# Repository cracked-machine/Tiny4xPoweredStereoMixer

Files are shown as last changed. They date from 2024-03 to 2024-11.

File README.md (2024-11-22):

HTML version of this page can be found [here](https://cracked-machine.github.io/Tiny4xPoweredStereoMixer/)

# Tiny 4 Channel Powered Stereo Mixer

A Tiny form-factor 4-channel stereo mixer for use with TV/PC/Turntable/Amplifer

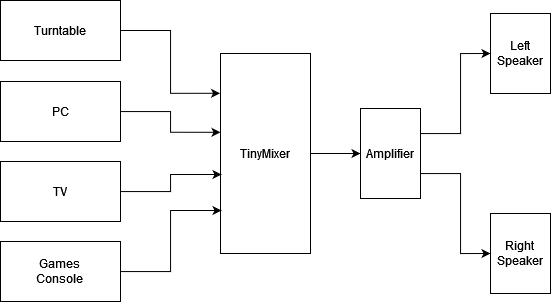
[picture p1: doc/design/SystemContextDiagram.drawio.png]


## Requirements

1. 4 stereo inputs
2. 1 stereo output
3. Inputs will all use stereo RCA/Phono connectors
4. volume controls for each of the 4 input channels
5. volume controls should be mounted in the front of the case
6. External power input shall be 9V DC
7. Internal power supply shall be +/-9V DC
8. Input signals shall be buffered
9. Volume controls for each channel shall  be independant and not subtract gain from the other channels.
10. Cross-talk between channels should be minimised.
  
## Top level Design

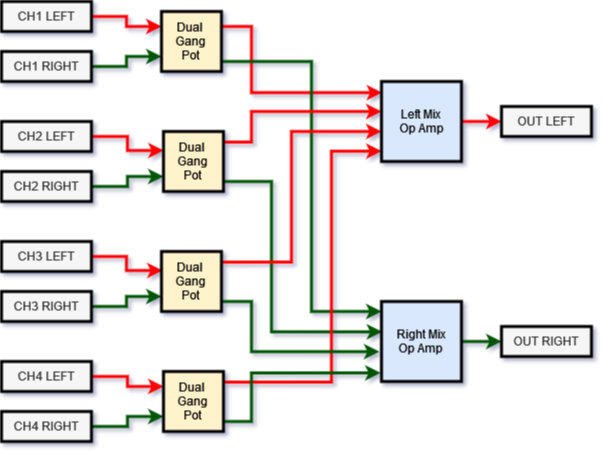
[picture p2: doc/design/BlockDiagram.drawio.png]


The opamps shall use [TL072](https://www.ti.com/lit/gpn/TL072H)

Using opamps to buffer the input signals and mix the channels together will ensure that the volume of each channel can be mixed independently from the others.

The design will implement an inverting opamp "virtual  ground" topology. The virtual ground refers to the inputs of the mixing opamp: the non-inverting input will be referenced to ground, which means the voltage at both opamp inputs will be referenced to ground because the potential _difference between inputs_ will always try to be zero. The absence of voltage at these inputs will prevent cross-talk between the channels. There is a far superior explanation of this concept at [sound-au.com](https://sound-au.com/articles/audio-mixing.htm#s3)

## Power Stage Design

The old PSU design for Rev A/B can be found in [OLDPSU.md](OLDPSU.md).

The negative voltage rail is generated from the positive rail using a [TPS54202](https://www.ti.com/lit/ds/symlink/tps54202.pdf) SMPS IC. This is normally a buck regulator. However, it can be configured to generate a negative voltage when pin 2 is clamped to ground, forcing pin 1 to a negative voltage.

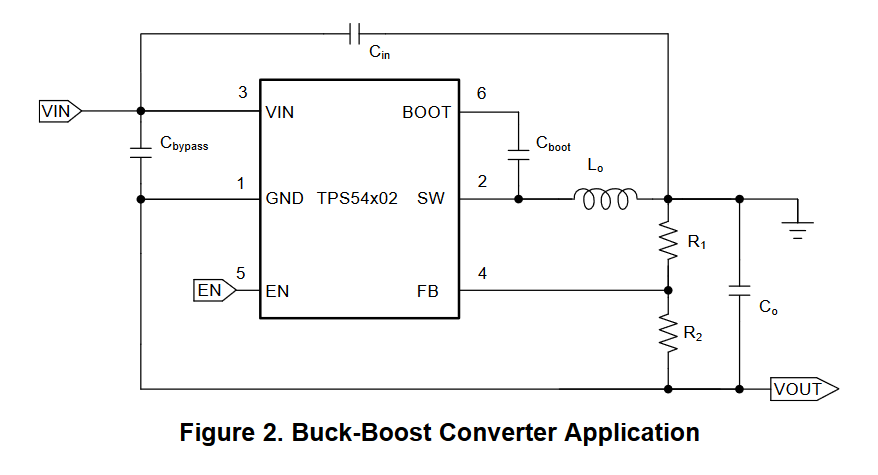
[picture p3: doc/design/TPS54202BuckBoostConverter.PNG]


Further details can be found in the [SLVA933](https://www.ti.com/lit/an/slva933/slva933.pdf) app note

### Soft Start

Unlike the LM2611, the TPS54202 has an internal soft start circuit. This can be seen in the Function Block Diagram of the [TPS54202](https://www.ti.com/lit/ds/symlink/tps54202.pdf) datasheet.

### Output Voltage 

Output voltage is selected using the voltage divider between pins 2 and 1, creating feedback into pin 4. This is very similar to the normal operation of this IC.

### Current Draw and Load Regulation

Output ripple is shown in the [SLVA933](https://www.ti.com/lit/an/slva933/slva933.pdf) app note as 5mV at no load and 20mV at 0.8A (see pages 21-22).

For my own test I [created a small board](https://github.com/cracked-machine/tps54202_inverting_breakout).
The original layout example with the new configuration violated the layout guiidelines from the [TPS54202](https://www.ti.com/lit/ds/symlink/tps54202.pdf) datasheet and proved to be noisy (240mV @ 0.6A). A second revision was made with a better layout that observed the guideline and was a significant improvement (80mv @ 0.6A).

Load regulation was around 5%, dropping from 12V to 11.4V @ 0.6A.

These results were acceptable so this PSU design was used.

## Schematics

<object data="doc/design/Tiny4xPoweredStereoMixer.pdf" type="application/pdf" width="100%" height="1000px">
    <embed src="doc/design/Tiny4xPoweredStereoMixer.pdf">
        <p>This browser does not support PDFs. Please download the PDF to view it: <a href="doc/design/Tiny4xPoweredStereoMixer.pdf">Download PDF</a>.</p>
    </embed>
</object>

## Layout

I used a 4 layer board so I could have a layer per voltage rail. This makes routing the traces significantly easier. I kept the board dimensions below 10cm to minimize manufacture costs. 

[Interactive BOM](https://cracked-machine.github.io/Tiny4xPoweredStereoMixer/doc/design/ibom.html)

## Enclosure

I abandoned the 3D printed enclosure idea and made the PCB to fit this [Hammond RM2005MTBK](https://www.hammfg.com/part/RM2005MTBK) clam shell enclosure.

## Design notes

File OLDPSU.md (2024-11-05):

## Power Stage Design

To power the buffer and mixer opamps, the design will need a power stage that supports 

1. Bi-polar or symmetric voltage rails that will allow "rail-to-rail" positive and negative headroom for the +/- audio signal.
2. Enough current for 5 (4 input + 1 mix) dual channel opamps. 

The simplest method for creating a negative voltage rail is....tonot create a negative voltage rail! In other words: use a voltage divider to create DC bias mid-point at the positive voltage rail. This has the effect of level-shifting the operating point of the opamp so that the ground reference is halfway between 0 volts and the positive rail. This requires only passive components - which is cheap - but also complicates the opamp design and can create issues with the opamp behaviour itself. You also have to be careful to filter out the DC from the input and output to prevent "pops" and damage to other devices such as speakers. I'm not a fan for these reasons. 

A better way is to actually create a new negative voltage rail from the existing positive rail. 

You can do this easily with a charge pump voltage regulator. This is an inductorless topology - already a benefit - but has very limited current capabilities - usually only 10-40mA - and is unregulated. This means the generated negative voltage is easily pulled down by the load if it consists of more than a couple of opamps. In practical terms, you could require a charge pump circuit for each opamp channel. Its also recommended to put a passive low pass filter on each charge pump output to prevent ripple. Each charge pump circuit requires roughly 6 components. In total that could be lot of components when you multiply that per opamp, per channel.

In the end I settled on the Cuk regulator topology using the [LM2611](https://www.ti.com/lit/ds/symlink/lm2611.pdf) converter IC. This is a buck-boost type regulator with an inverted output rail. And it comes in a tiny SOT-23 footprint!

Here is the reference design from the datasheet. 

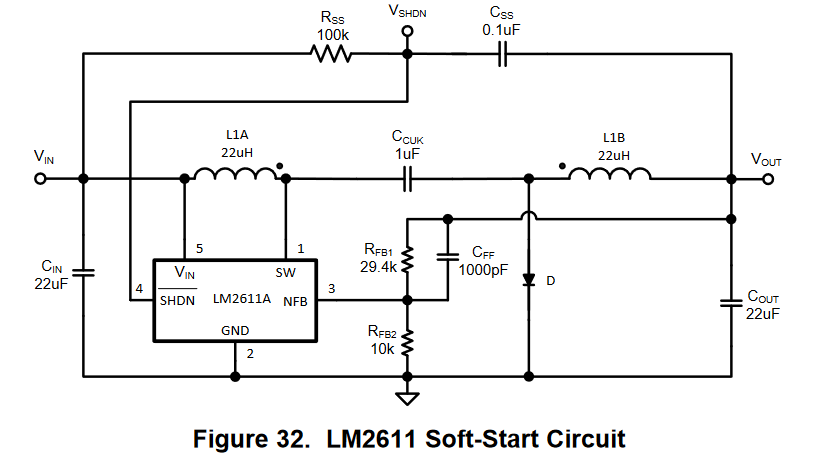
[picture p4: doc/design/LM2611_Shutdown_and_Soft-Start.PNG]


### Soft Start

Since the IC doesn't contain a soft-start feature, required additional circuitry is shown in the image above. Without the soft-start, the in-rush current will significantly exceed the current consumption specification. In fact, it tripped the lab power supply current protection; I thought the board had a short. I had to adjust the current protection to to more than 1 Amp to allow the circuit to power up correctly! Not great if you're trying to prevent lab accidents. Adding the soft-start circuitry meant that the board powered up peaking at 60mA...which is a massive drop and far mroe acceptable. Below is a screenshot of the scope capture. Negative power rail from the [LM2611](https://www.ti.com/lit/ds/symlink/lm2611.pdf) is Yellow, output signal is shown in Blue. The power rail is now much more gradual, rather than a sudden off-on transition. The datasheet implied there would still be a voltage spike at the peak of the turn on transtition but looking at the capture below, it would seem that the voltage spike with the soft-start has also been minimised greatly.

However, a large voltage spike remains on the output signal when the board is powered up. This is the culprit for the pop or thump you often hear in the output device speakers. Not sure what is the best solution here: Maybe caps on the output path, maybe delayed opamp start or maybe just turn the board on __before__ any down stream amplifiers.



### Output Voltage 

The output voltage can be adjusted using the negative feedback resistors RFB1 and RFB2.
Rather unhelpfully the datasheet did not contain the equation to calculate the resistor divider values. I found the equation on a post in the TI forums. Maybe this is EE101 but I can't reconcile that omission in my head.

|VREF|RFB1|RFB2|VOUT|
|-|-|-|-|
|-1.23v|2.2K|22k|VREF * (1 + (RFB2/RFB1)  = -13.5v|

Note, that the resistors must not exceed 50Kohm. According to the datasheet this is due to leakage at the NFB pin.

Using common resistor values it was only possible to reach just under 12v or quite a bit over. So I opted for the latter. Better to have a larger power supply swing than too little. It also gives some allowance for load regulation.

### Current Draw and Load Regulation

The application curve from the datasheet shows that with -12V output, the max current it could provide would be 400mA.

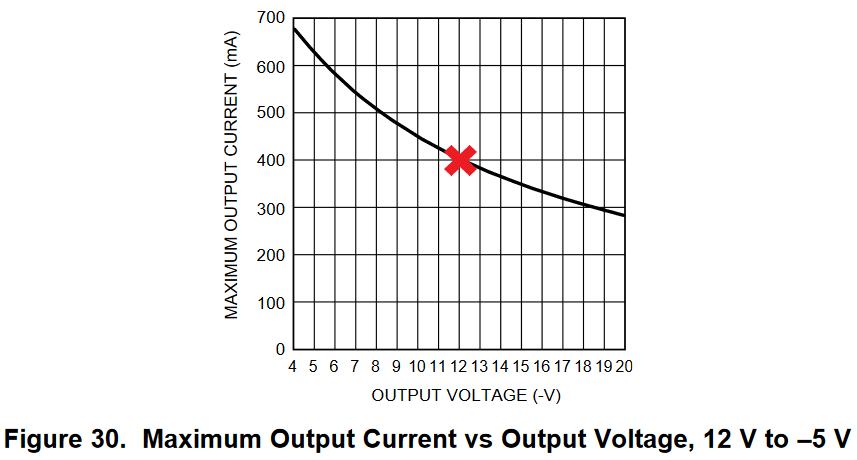
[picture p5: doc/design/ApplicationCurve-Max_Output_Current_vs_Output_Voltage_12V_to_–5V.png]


Bearing in mind the quiescent voltage of each TL072 opamp is only 1.2mA, this is overkill. However, during active use, the current will certainly be higher. 

The datasheet boasts `Better Regulation Than a Charge Pump` but then fails to offer any evidence elsewhere in the datasheet. I have no doubt that this claim is broadly true - charge pumps have abysmal load regulation. However, I'm always sceptical about the claims of load regulation on these regulator IC's. Usually when a company omits test results from the datasheet it's because the results were not so great.  

Below are the load regulation test results from 10mA to 400mA. Test was run using a [TENMA 72-13210](https://uk.farnell.com/tenma/72-13210/dc-electronic-load-prog-30a-120v/dp/2848407)

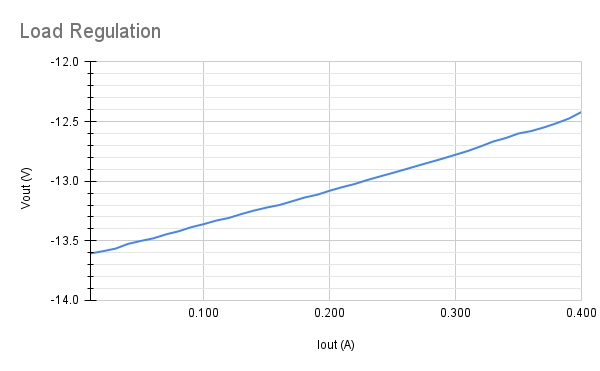
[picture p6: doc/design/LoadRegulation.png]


The negative voltage rail dropped by ~1.2V at the max load of 400mA, which is a 10% drop. That's actually not __too__ bad. Although if I had picked < 12V output I might not be so forgiving. Still, better than a charge pump...

---

Final note on the Cuk topology: There don't appear to be many IC's out there that support this type of regulator. Either it's overlooked or it has some major drawback that I'm missing here.

I noticed later it is possible to create an inverting regulator from a synchronous buck regulator.  [See this app note from TI](https://www.ti.com/lit/an/slva458b/slva458b.pdf). However, there are significant limitations:

- the input voltage
needs to be higher than the minimum required voltage for the device
- The maximum allowable output
voltage is limited by the maximum Vdev minus the maximum input voltage.
- The maximum load current cannot be more than the maximum current through the internal switches.

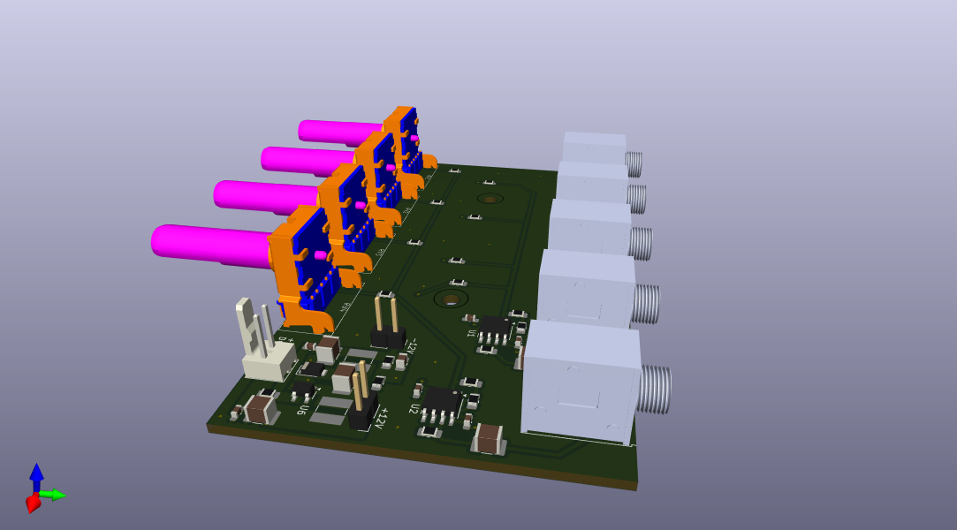
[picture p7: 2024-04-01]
doc/design/Tiny4xPoweredStereoMixerRender.png

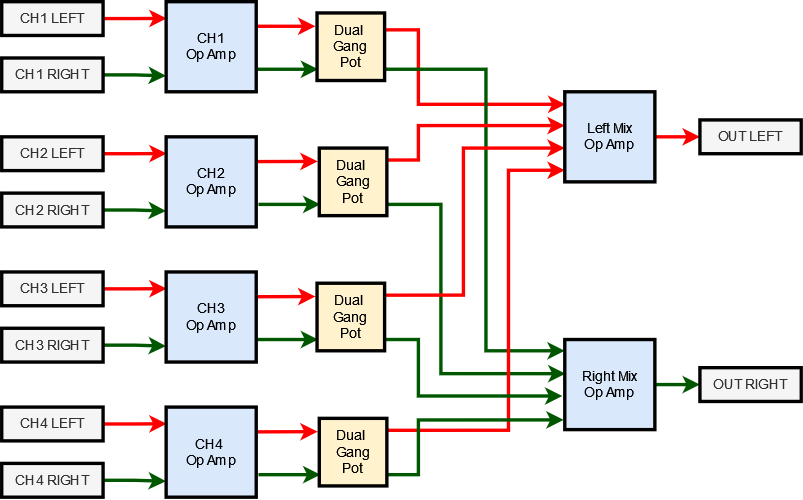
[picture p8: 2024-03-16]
doc/design/BlockDiagram.png

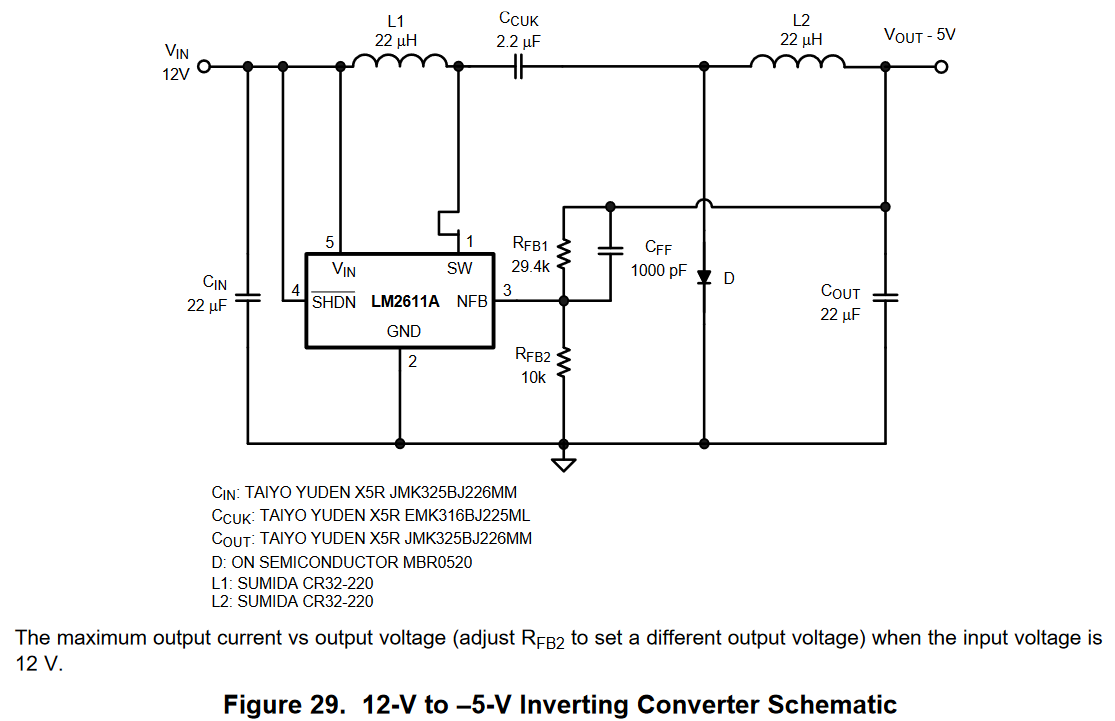
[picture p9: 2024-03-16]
doc/design/12V_to_–5V_Inverting_Converter.PNG

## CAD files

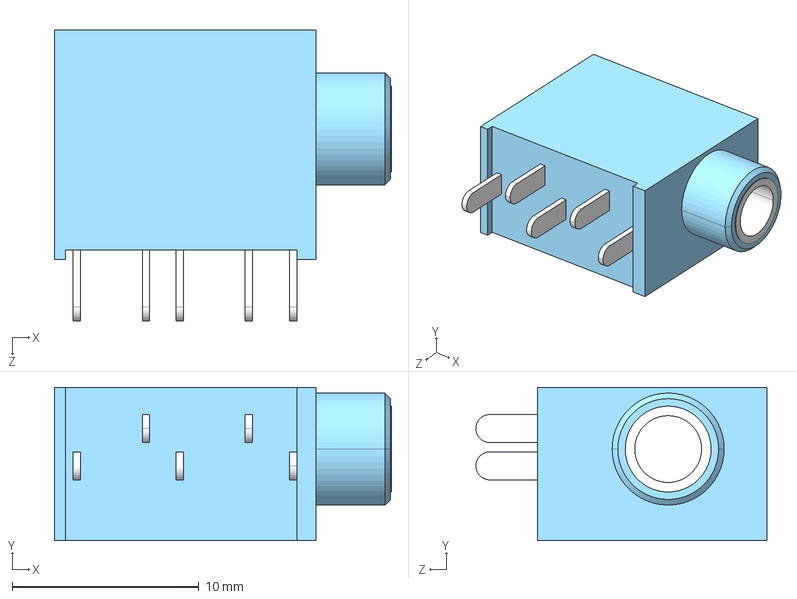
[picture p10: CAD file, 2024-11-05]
kicad/Footprints/Same_Sky_SJ1-3535NG-BE.step
18.1 x 8.20 x 15.6 mm

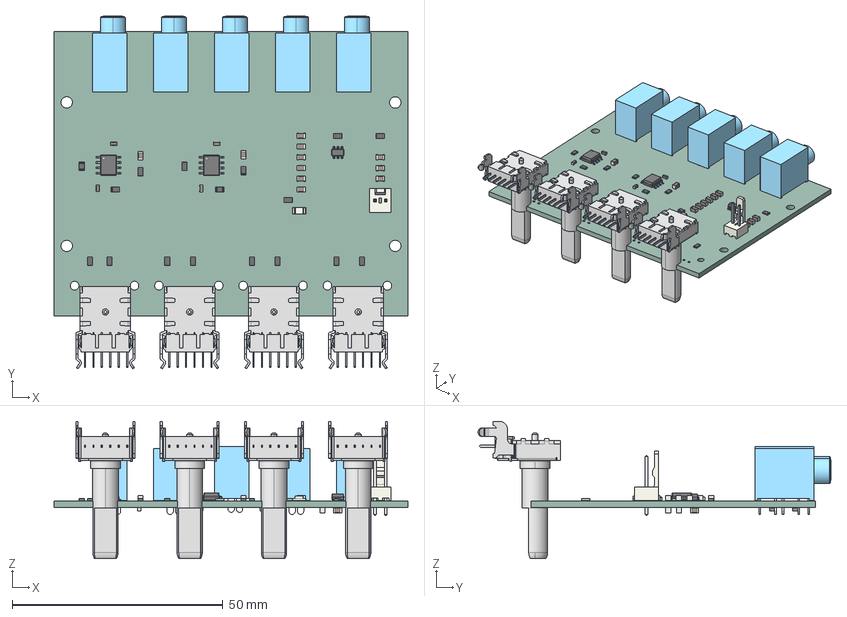
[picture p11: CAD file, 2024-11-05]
kicad/Tiny4xPoweredStereoMixer.step
84.0 x 83.7 x 32.6 mm
R_0805_2012Metric x 17
C_0805_2012Metric x 14
SOIC_8_39x49mm_P127mm x 2
C_0603_1608Metric x 12
CUI_DEVICES_SJ1-3535NG-BE x 5
SOT_23_6
Molex_AE_6410_02A
Tiny4xPoweredStereoMixer 1.33.1 x 4
LED_1206_3216Metric
Tiny4xPoweredStereoMixer_PCB

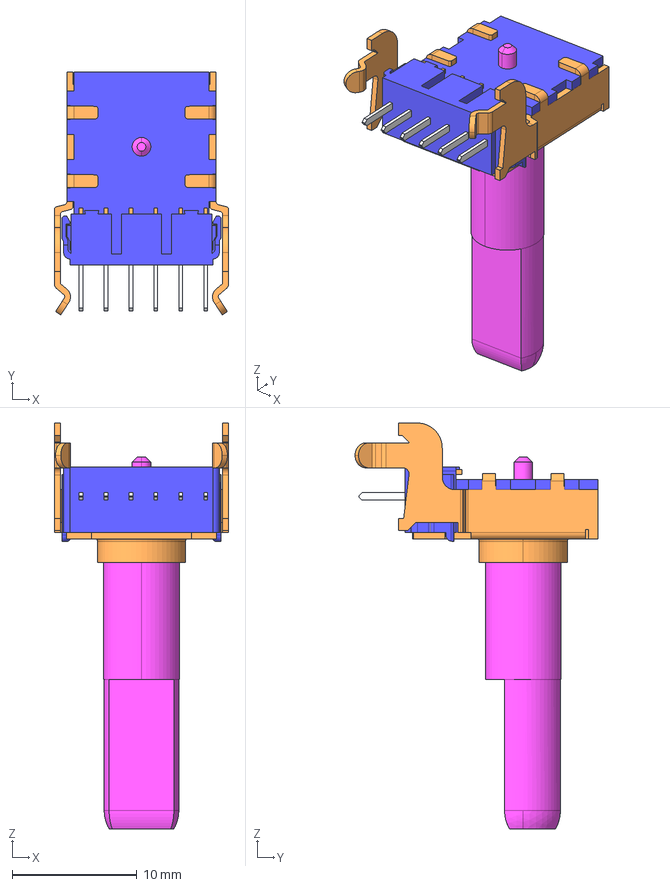
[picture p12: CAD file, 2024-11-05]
kicad/Footprints/RK12L12-F30H2.STEP
14.0 x 19.5 x 32.6 mm

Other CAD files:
kicad/Footprints/RK12L12-F30H.STEP

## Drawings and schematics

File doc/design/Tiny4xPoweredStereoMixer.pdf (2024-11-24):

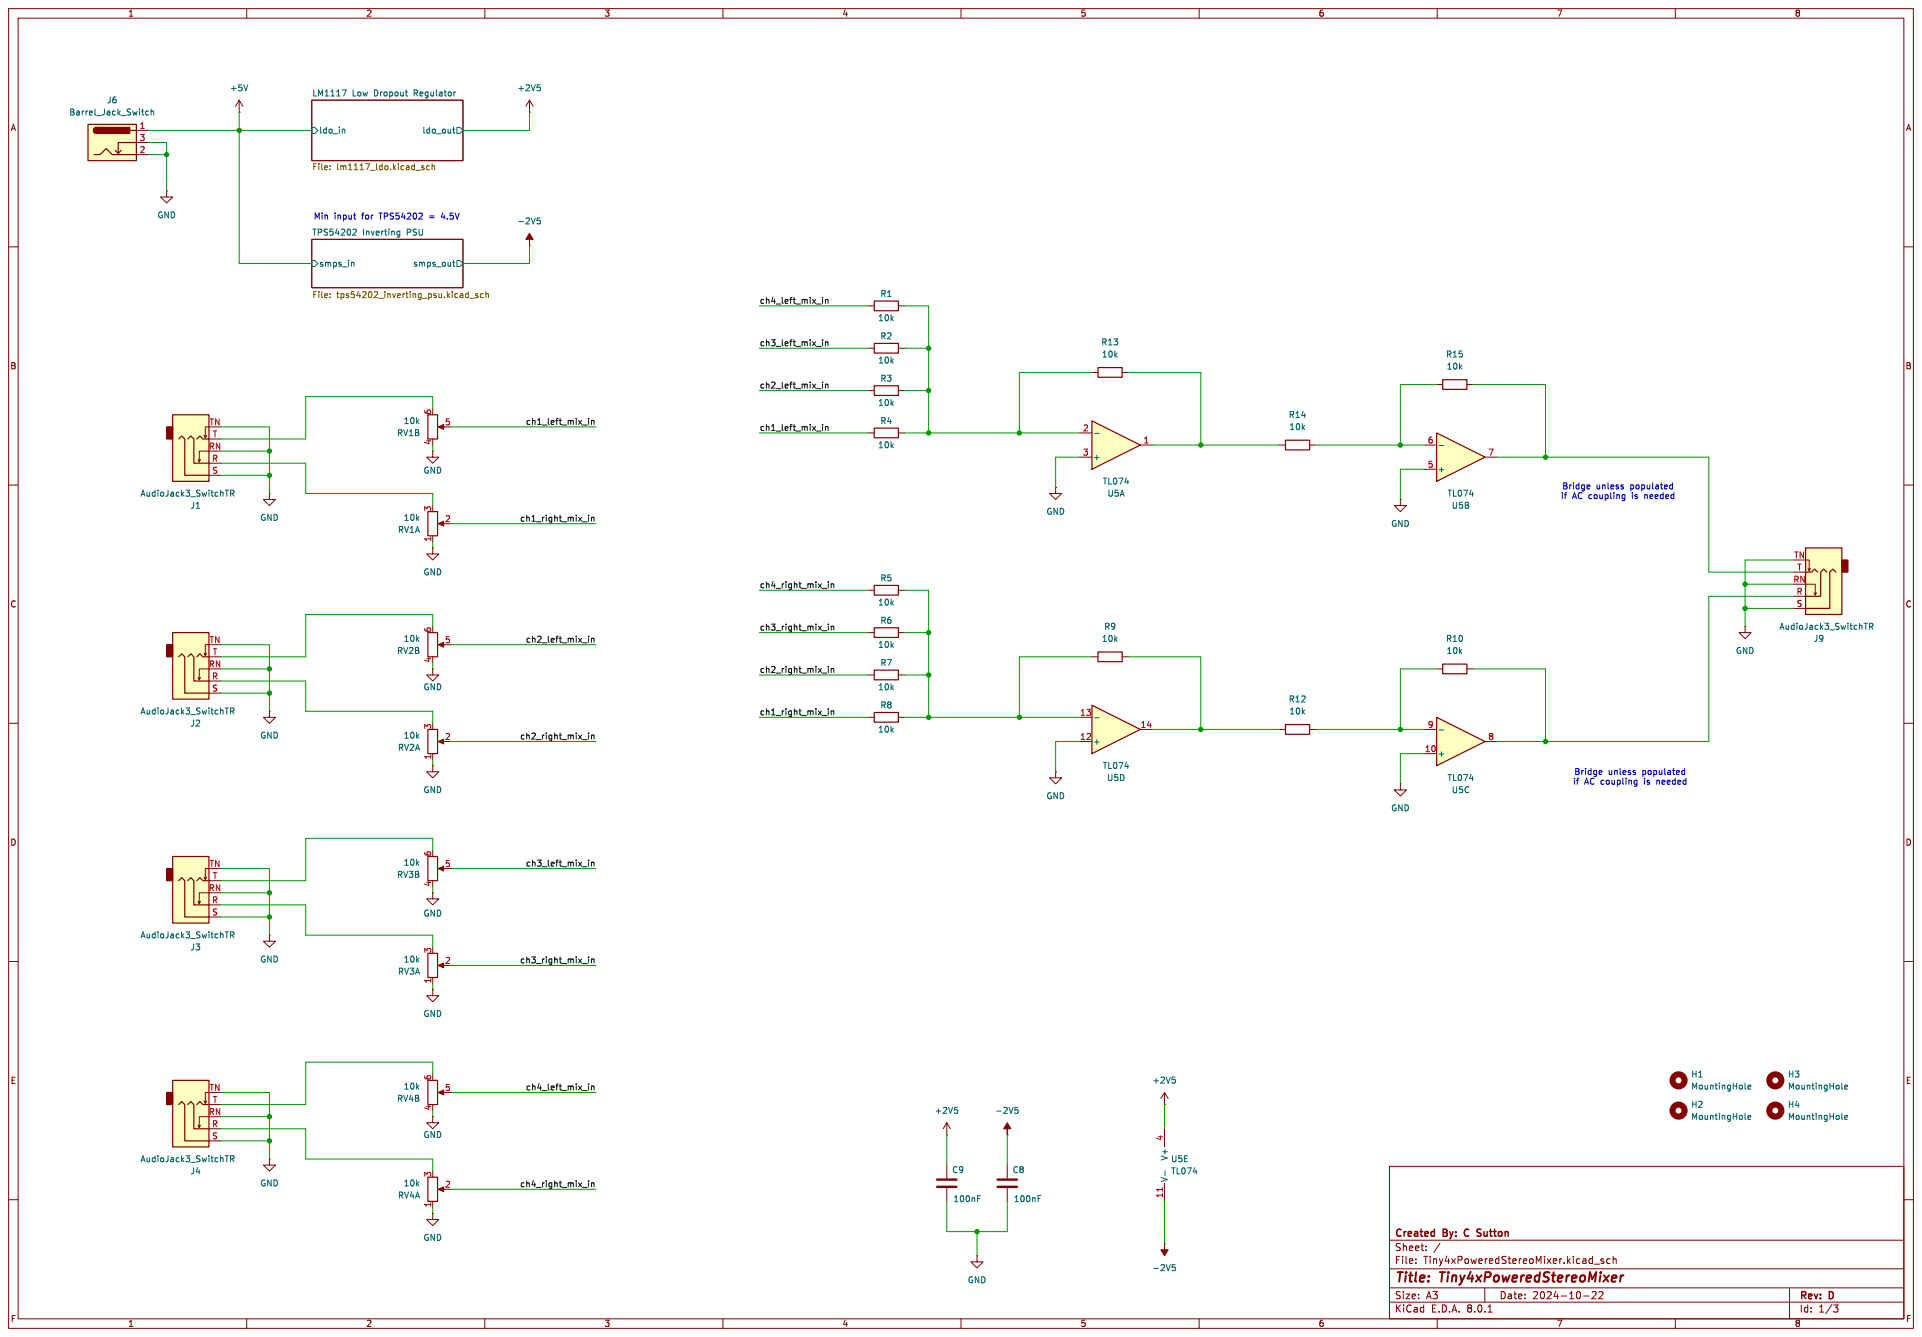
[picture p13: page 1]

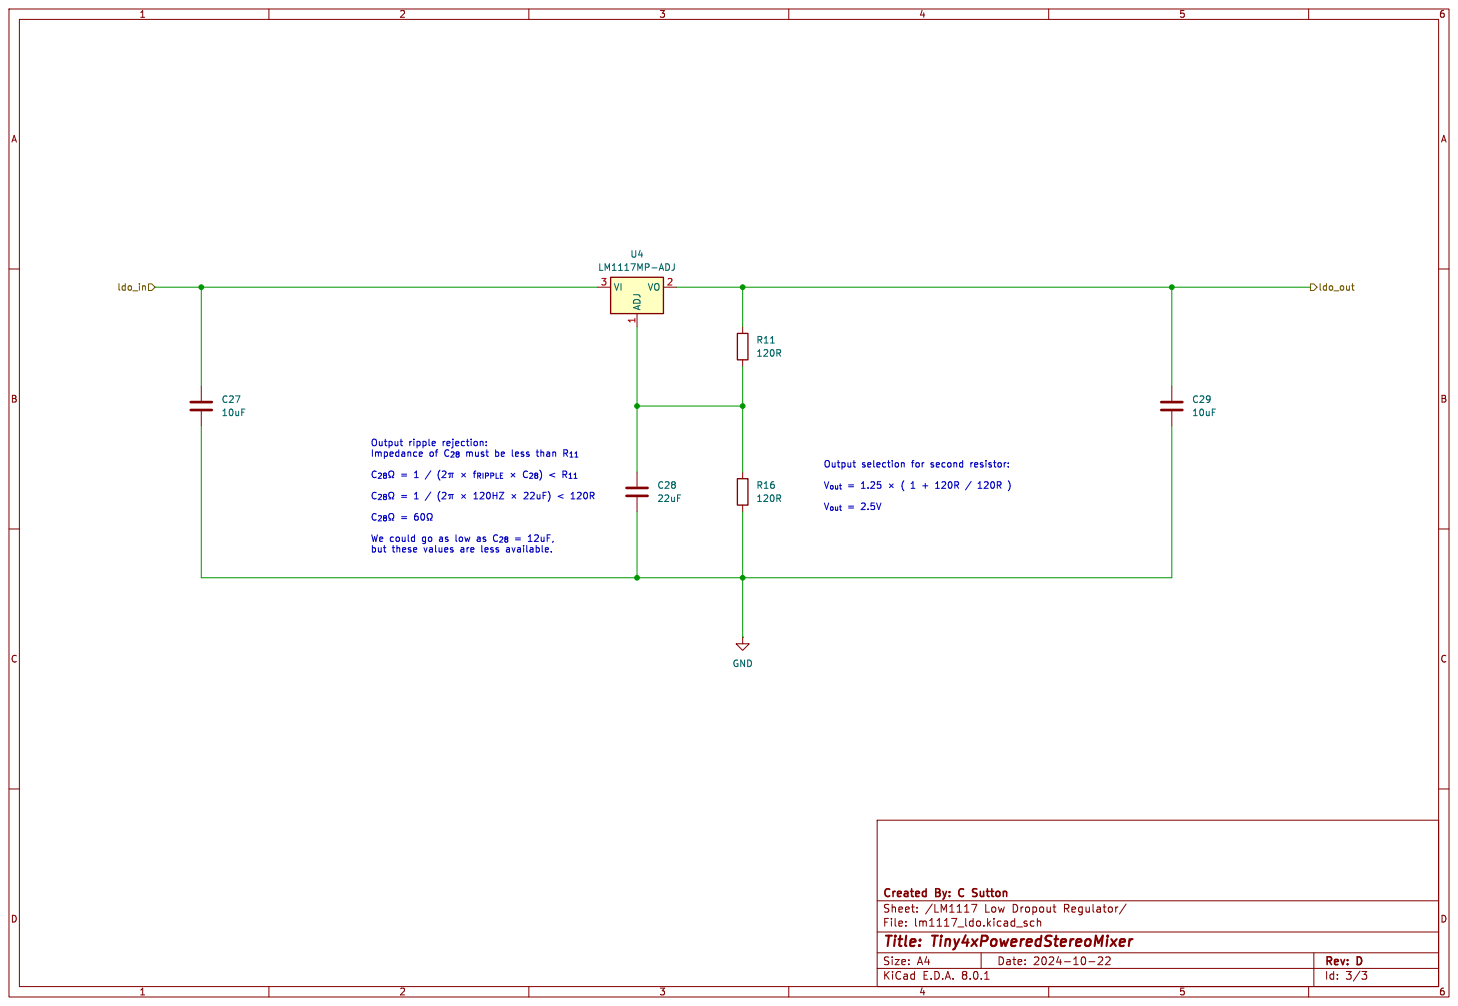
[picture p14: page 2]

þÿC_{28}© = 1 / þÿ(2Àþÿ×f_{RIPPLE} þÿ×C_{28})< R_{11}

þÿC_{28}© = 1 / þÿ(2Àþÿ×120HZ þÿ×22uF) < 120R

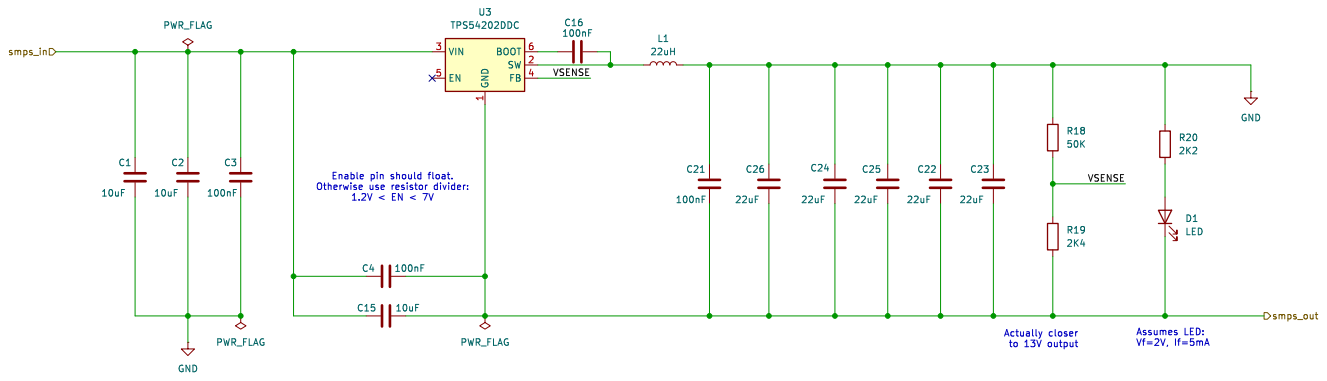
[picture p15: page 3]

1 SW 2 VIN 3 FB 4 EN 5 BOOT 6 U3 TPS54202DDC

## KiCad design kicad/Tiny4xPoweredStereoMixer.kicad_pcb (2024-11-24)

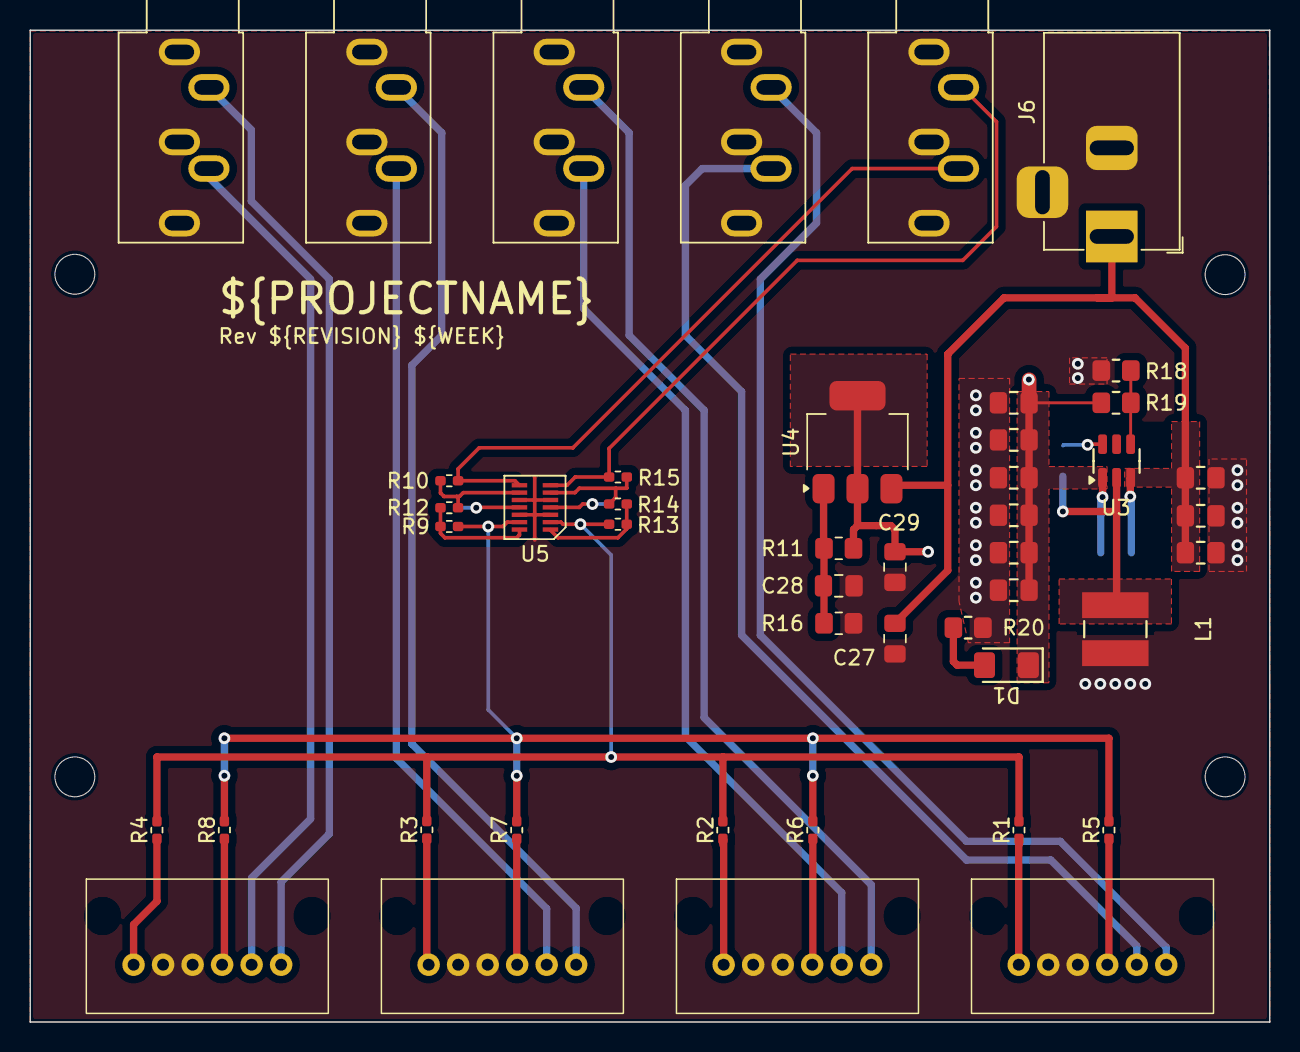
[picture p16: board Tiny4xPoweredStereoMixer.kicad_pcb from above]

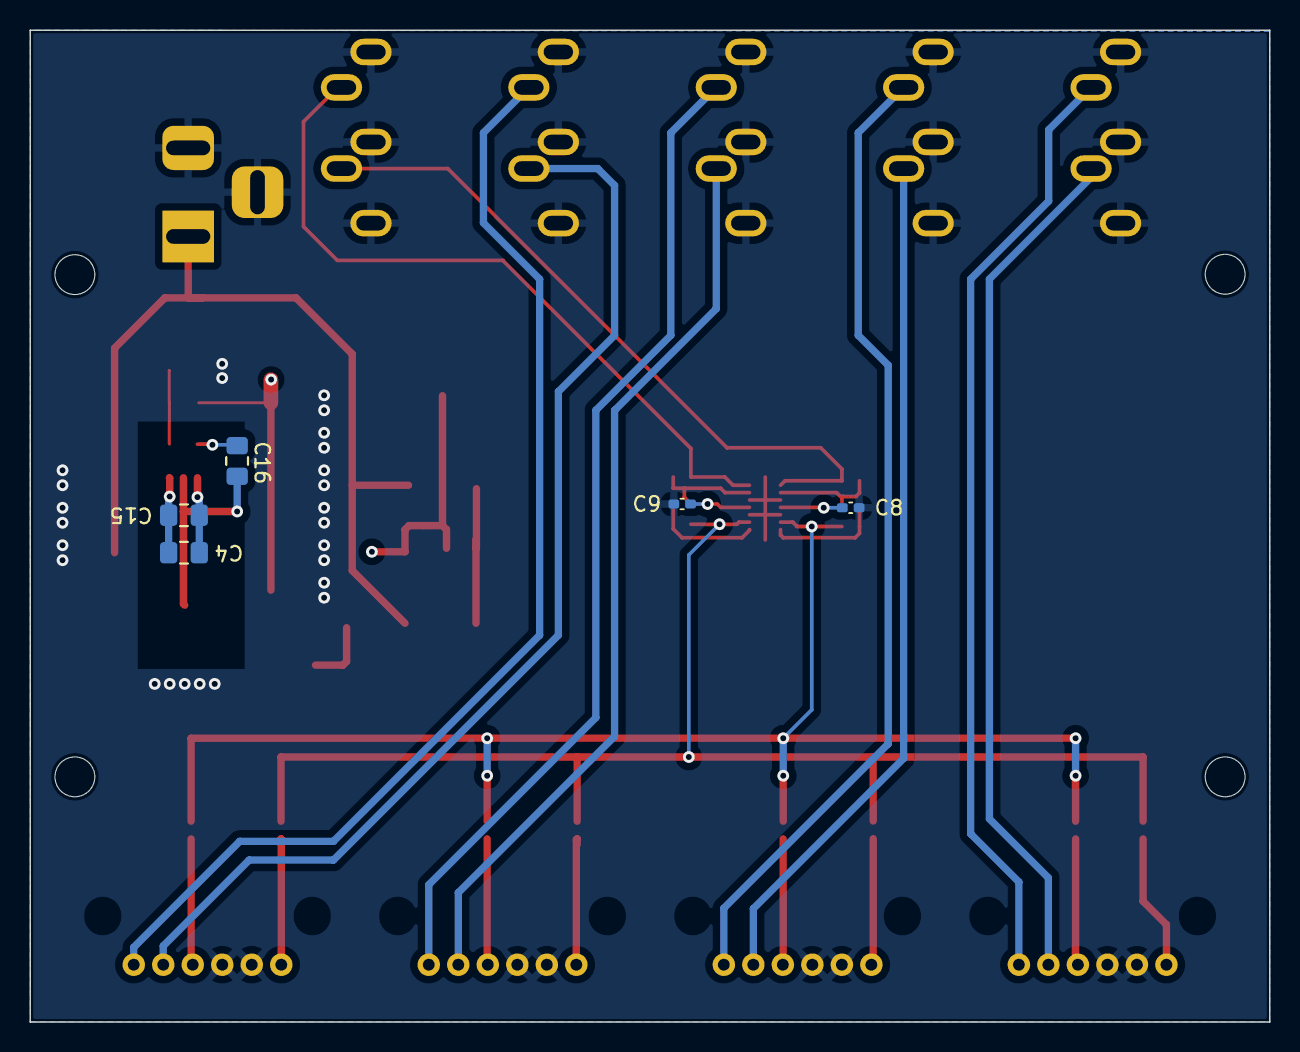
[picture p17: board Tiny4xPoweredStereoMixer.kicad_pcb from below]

Board: 4 copper layers, 84.0 x 67.2 mm, 55 parts (5 on the bottom side), 33 nets.

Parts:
C1, C2, C15, C27, C29: 10uF; C_0805_2012Metric_Pad1.18x1.45mm_HandSolder
C3, C4, C16, C21: 100nF; C_0805_2012Metric_Pad1.18x1.45mm_HandSolder
C8, C9: 100nF; C_0402_1005Metric_Pad0.74x0.62mm_HandSolder
C22, C23, C24, C25, C26, C28: 22uF; C_0805_2012Metric_Pad1.18x1.45mm_HandSolder
D1: LED; LED_1206_3216Metric_Pad1.42x1.75mm_HandSolder
H1, H2, H3, H4: MountingHole; MountingHole_2.7mm_M2.5
J1, J2, J3, J4, J9: AudioJack3_SwitchTR; Jack_3.5mm_CUI_SJ1-3535NG_Horizontal
J6: Barrel_Jack_Switch; BarrelJack_Horizontal
L1: 22uH; L_Ferrocore_DLG-0403
R1, R2, R3, R4, R5, R6, R7, R8, R9, R10, R12, R13, R14, R15: 10k; R_0402_1005Metric_Pad0.72x0.64mm_HandSolder
R11, R16: 120R; R_0805_2012Metric_Pad1.20x1.40mm_HandSolder
R18: 50K; R_0805_2012Metric_Pad1.20x1.40mm_HandSolder
R19: 2K4; R_0805_2012Metric_Pad1.20x1.40mm_HandSolder
R20: 2K2; R_0805_2012Metric_Pad1.20x1.40mm_HandSolder
RV1, RV2, RV3, RV4: 10k; Alps_RK12L12_Double_Horizontal
U3: TPS54202DDC; SOT-23-6
U4: LM1117MP-ADJ; SOT-223-3_TabPin2
U5: TL074; SOIC-14

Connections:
+2V5: C9.1, C29.1, R11.1, U4.2 (VO), U5.4 (V+)
+5V: C1.1, C2.1, C3.1, C4.1, C15.1, C27.1, J6.1, U3.3 (VIN), U4.3 (VI)
-2V5: C4.2, C8.1, C15.2, C21.2, C22.2, C23.2, C24.2, C25.2, C26.2, D1.1 (K), R19.1, U3.1 (GND), U5.11 (V-)
/TPS54202 Inverting PSU/VSENSE: R18.1, R19.2, U3.4 (FB)
/ch1_left_mix_in: R4.1, RV1.5
/ch1_right_mix_in: R8.1, RV1.2
/ch2_left_mix_in: R3.1, RV2.5
/ch2_right_mix_in: R7.1, RV2.2
/ch3_left_mix_in: R2.1, RV3.5
/ch3_right_mix_in: R6.1, RV3.2
/ch4_left_mix_in: R1.1, RV4.5
/ch4_right_mix_in: R5.1, RV4.2
GND: C1.2, C2.2, C3.2, C8.2, C9.2, C21.1, C22.1, C23.1, C24.1, C25.1, C26.1, C27.2, C28.2, C29.2, J1.RN, J1.S, J1.TN, J2.RN, J2.S, J2.TN, J3.RN, J3.S, J3.TN, J4.RN, J4.S, J4.TN, J6.2, J6.3, J9.RN, J9.S, J9.TN, L1.2, R16.2, R18.2, R20.2, RV1.1, RV1.4, RV2.1, RV2.4, RV3.1, RV3.4, RV4.1, RV4.4, U5.3 (+), U5.5 (+), U5.10 (+), U5.12 (+)
unnamed: D1.2 (A), R20.1
unnamed: J1.R, RV1.3
unnamed: J1.T, RV1.6
unnamed: J2.R, RV2.3
unnamed: J2.T, RV2.6
unnamed: J3.R, RV3.3
unnamed: J3.T, RV3.6
unnamed: J4.R, RV4.3
unnamed: J4.T, RV4.6
unnamed: J9.R, R10.2, U5.8
unnamed: J9.T, R15.2, U5.7
unnamed: R9.2, R12.1, U5.14
unnamed: R13.2, R14.1, U5.1
unnamed: C16.1, U3.6 (BOOT)
unnamed: C16.2, L1.1, U3.2 (SW)
unnamed: C28.1, R11.2, R16.1, U4.1 (ADJ)
unnamed: R1.2, R2.2, R3.2, R4.2, R13.1, U5.2 (-)
unnamed: R14.2, R15.1, U5.6 (-)
unnamed: R10.1, R12.2, U5.9 (-)
unnamed: R5.2, R6.2, R7.2, R8.2, R9.1, U5.13 (-)

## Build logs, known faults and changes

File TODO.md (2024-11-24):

- [X] UPdate PSU to +/- 2.5v from +5V
  - [X] Add LDO to get +2.5v
  - [X] Use TPS54202 to get -2.5v
- [X] Update 2 x TL072 to 1 x TL074 (SOT23-14)
- [X] Add back panel DC barrel jack onto the PCB
- [ ] Add front panel led push switch for power

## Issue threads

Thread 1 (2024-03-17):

Add barrel jack connector

cracked-machine, 2024-03-17:

cracked-machine, 2024-03-31:
Layout uses a KK256 connector. This will allow the DC socket to be connected anywhere on the enclosure

Closed 2024-03-31.

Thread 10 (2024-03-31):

add pull down resistors to opamp input to prevent hum when inputs are not connected/active

cracked-machine, 2024-03-31:

cracked-machine, 2024-04-01:
replaced phono connectors with 3.5mm jack connectors (which have built in ground switches)

Closed 2024-04-01.

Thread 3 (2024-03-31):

Fix potentiometer direction

cracked-machine, 2024-03-31:
Pots currently lower volume when turned CW. This should be the other way around:

- CW volume increase
- CCW volume decrease

Closed 2024-03-31.

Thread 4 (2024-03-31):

power supply in rush current

cracked-machine, 2024-03-31:
When unit is turned on, the power supply takes a very large gulp of current. This causes the current protection to trip on the lab power supply and will probably require a larger wall transformer when used in the wild. Would be good to lower this in rush by lowering the current output of the SMPS. Probably by lowering the caps/inductors. Needs more research.

cracked-machine, 2024-03-31:
See **8.2.6 Shutdown and Soft-Start** in LM2611 Datasheet. This was tested with a sacrificial board. The lab power supply current limit was no longer tripped by the in rush of the LM2611. The limit was able to be set as low as 60mA (50mA is the quiescent current draw of the 5 opamps on the board). Great result!

Closed 2024-03-31.

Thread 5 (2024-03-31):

Amp protection from DC transients

cracked-machine, 2024-03-31:
When audio sources are turned off with the mixer/amp powered, large thumps are heard in the speakers. This is not caused by the mixer. Ideally we could block these DC transients. Maybe AC coupling in the mixer.

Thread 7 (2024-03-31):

Add output capacitor for AC coupling

cracked-machine, 2024-03-31:
Experiment with AC coupling cap to remove any DC pops from audio sources passing into output (amp and speakers)

cracked-machine, 2024-04-01:
added 100nF 0603 caps to each input and 10uF 1210 caps to output

Closed 2024-04-01.

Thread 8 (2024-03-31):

Position the input voltage connector footprint closer to the board edge to allow for better physical connector (molex kk)

cracked-machine, 2024-03-31:

Closed 2024-03-31.

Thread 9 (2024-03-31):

replace 10K resistors with array

cracked-machine, 2024-03-31:

cracked-machine, 2024-03-31:
5x10K SMD resistor arrays are not common

Closed 2024-03-31.

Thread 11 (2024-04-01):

Add ground test point

cracked-machine, 2024-04-01:
Preferably a through hole loop

Closed 2024-04-01.

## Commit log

2024-03-16 upload kicad project
    [BufferOpAmp.kicad_sch, MixerOpAmp.kicad_sch, PowerSupply.kicad_sch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]
2024-03-16 switched slashes
2024-03-17 main schematic done, layout started
    [BufferOpAmp.kicad_sch]
2024-03-17 added barrel jack connector to schema
    [Tiny4xPoweredStereoMixer.kicad_sch]
2024-03-17 added connectors/jumper for isolating the +/-12V power lines
    [Tiny4xPoweredStereoMixer.kicad_sch]
2024-03-17 updated powerflags
    [Tiny4xPoweredStereoMixer.kicad_sch]
2024-03-17 add mount holes
    [Tiny4xPoweredStereoMixer.kicad_sch]
2024-03-17 positioned +/-12v connectors
    [Tiny4xPoweredStereoMixer.kicad_pcb]
2024-03-17 completed reva layout
    [BufferOpAmp.kicad_sch, MixerOpAmp.kicad_sch, Tiny4xPoweredStereoMixer-BOM.csv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]
2024-03-17 updated pdf schematic
2024-03-31 updated cuk converter negative feedback resistors
    [BufferOpAmp.kicad_sch, MixerOpAmp.kicad_sch, Tiny4xPoweredStereoMixer.kicad_pcb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]
2024-03-31 - Fixed in-rush current problem using soft-start design. https://github.com/cracked-machine/Tiny4xPoweredStereoMixer/issues/4 - Fixed reversed pots. https://github.com/cracked-machine/Tiny4xPoweredSt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
    [BufferOpAmp.kicad_sch, MixerOpAmp.kicad_sch, Tiny4xPoweredStereoMixer.kicad_pcb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]
2024-03-31 Refactored schematic into single page (except PSU)
    [BufferOpAmp.kicad_sch, MixerOpAmp.kicad_sch, PowerSupply.kicad_sch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]
2024-03-31 updated schematics
2024-04-01 added RK12L2 pot footprint
2024-04-01 - updated pots to rk12l12
    [PowerSupply.kicad_sch, Tiny4xPoweredStereoMixer.kicad_pcb, Tiny4xPoweredStereoMixer.kicad_sch]
2024-04-01 replaced phono connectors with 3.5mm stereo jack connectors so that unplugged connections are switched to ground
    [CUI_DEVICES_SJ1-3535.step, PowerSupply.kicad_sch, Tiny4xPoweredStereoMixer.kicad_pcb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]
2024-04-01 completed revb layout
    [Tiny4xPoweredStereoMixer-B_Cu.gbr, Tiny4xPoweredStereoMixer-B_Mask.gbr, Tiny4xPoweredStereoMixer-B_Paste.gbr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]
2024-04-13 updated schematic pdf
2024-04-13 updated pcb layout project file
    [Tiny4xPoweredStereoMixer.kicad_pcb]
2024-04-18 updated schematic to use TPS54202
    [Tiny4xPoweredStereoMixer.kicad_pcb, Tiny4xPoweredStereoMixer.kicad_sch, tps54202_inverting_psu.kicad_sch]
2024-10-21 Added extra output capacitor footprints to psu
    [tps54202_inverting_psu.kicad_sch]
2024-10-21 Set PCB rules and edded outline for Hammond RM2005S enclosure
    [Tiny4xPoweredStereoMixer.kicad_pcb]
2024-10-22 Finished RevC layout
    [Tiny4xPoweredStereoMixer.kicad_pcb, Tiny4xPoweredStereoMixer.kicad_sch, tps54202_inverting_psu.kicad_sch]
2024-10-23 changed pot from linear to log
    [Tiny4xPoweredStereoMixer.kicad_sch]
2024-11-05 rev c layout complete
    [CUI_DEVICES_SJ1-3535.step, RK12L12-F30H.STEP, RK12L12-F30H2.STEP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]
2024-11-05 updated main
    [CUI_DEVICES_SJ1-3535.step, PowerSupply.kicad_sch, RK12L12-F30H.STEP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]
2024-11-23 PSU now uses +/- 2.5V; Added barrel jack; updated layout
    [Tiny4xPoweredStereoMixer.kicad_pcb, Tiny4xPoweredStereoMixer.kicad_sch, lm1117_ldo.kicad_sch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]
2024-11-23 Created missing SOT-23-THIN-14 footprint; Replaced 2xTL072 with 1xTL074; updated layout
    [Tiny4xPoweredStereoMixer.kicad_pcb, Tiny4xPoweredStereoMixer.kicad_sch]
2024-11-24 changed voltage rails to +/-5V; changed PSU feedback resistor to provide -5V
    [Tiny4xPoweredStereoMixer.kicad_pcb, Tiny4xPoweredStereoMixer.kicad_sch, tps54202_inverting_psu.kicad_sch]
2024-11-24 Revert "changed voltage rails to +/-5V; changed PSU feedback resistor to provide -5V"
    This reverts commit 87719da26a309bbde2d2f76146bcb1e510287c62.
    [Tiny4xPoweredStereoMixer.kicad_pcb, Tiny4xPoweredStereoMixer.kicad_sch, tps54202_inverting_psu.kicad_sch]
